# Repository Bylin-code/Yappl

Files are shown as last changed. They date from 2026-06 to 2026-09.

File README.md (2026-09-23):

# Yappl

Yappl is a small voice-journaling device built around a Seeed Studio XIAO ESP32S3. It has an animated face, a microphone, a button, a reminder light, and a piezo. Recordings stream over Wi-Fi to a backend running on your computer, where they are saved, transcribed locally, and optionally summarized with an AI provider. You can play back recordings and read your journal in a browser.

Build and test the electronics on a breadboard first. Follow the configuration, upload, and backend steps below and complete a test recording before moving the electronics into the printed chassis.

## 1. Bill of materials

| Quantity | Part | Notes |
| --- | --- | --- |
| 1 | Seeed Studio XIAO ESP32S3 | Standard board with 8 MB flash and 8 MB PSRAM; connect its Wi-Fi antenna. |
| 1 | SH1107 128 × 128 I2C OLED | Address `0x3C`, compatible with 3.3 V power and logic. An SSD1306 or SPI display is not a drop-in replacement. |
| 1 | INMP441 I2S microphone breakout | External microphone; this firmware does not use the Sense board's built-in microphone. |
| 1 | Normally open momentary pushbutton | Use contacts that connect only when pressed. |
| 1 | LED | External status/reminder LED; choose your preferred color. |
| 1 | Small passive piezo element | Not an active buzzer, magnetic buzzer, or speaker. |
| 1 | Bare photoresistor (LDR) | Room-light sensor. |
| 1 | 330 Ω resistor | LED current limiting. |
| 1 | 100 Ω resistor | Piezo series resistor. |
| 2 | 10 kΩ resistors | One for the light-sensor divider and one for the button pulldown. |
| 1 | USB-C data cable | Powers the board and uploads firmware; a charge-only cable cannot upload. |
| As needed | Breadboard, jumper wires, and headers | For the initial working prototype. |
| As needed | Insulated hookup wire, solder, and heat-shrink | For final connections inside the chassis. |
| 1 set | Printed enclosure parts | Files and printing instructions below. |
| As needed | FDM filament | Your choice of colors; use different colors for the cap and dots. |

You will also need an FDM printer, a soldering iron and basic hand tools, and a computer to upload firmware and run the backend. A multimeter is useful for checking continuity before power-up. Keep the backend computer powered on and awake during recording.

## 2. Print the enclosure

I'm using a **Bambu A1**, but **any FDM printer should work**. Use Bambu Studio for the A1 or your printer's slicer.

Print one of each:

- [`cad/body.stl`](cad/body.stl)
- [`cad/chassis-bottom.stl`](cad/chassis-bottom.stl)
- [`cad/chassis-top.stl`](cad/chassis-top.stl)
- The assembled hat from [`cad/hat-parts/`](cad/hat-parts/): `main-cap.stl` and `dot1.stl` through `dot8.stl`.

For the hat:

1. Select **all nine meshes** in `cad/hat-parts/` and import them together.
2. When prompted, import them as **a single object with multiple parts**. Preserve their relative positions; do not arrange each mesh independently on the plate.
3. Expand that object in the slicer's object list. Assign `main-cap.stl` one filament color and the `dot[x].stl` parts a different color. **The colors can be whatever you like.** The dots can share a color or use several colors, as long as they contrast with the cap.
4. Slice and preview the hat to confirm that the dots are correctly positioned and have the intended colors.

Use your printer's material profile and print the models at their original scale. PLA and a 0.20 mm layer height are reasonable starting points, not a required or validated print profile. Check orientation, bed contact, overhangs, and any required supports in the preview before printing. Test-fit the chassis and your electronics before permanent assembly; module dimensions and printer tolerances can vary.

Automatic multicolor printing requires suitable filament-changing hardware, such as an AMS Lite on the A1. With a single-color printer, you can print the assembled hat in one color and paint the dots afterward.

## 3. Wire and test on a breadboard

**Disconnect USB before changing wiring.** Power the XIAO through USB-C. Connect its `3V3` pin to the breadboard positive rail and `GND` to the ground rail. All components must share ground. Use **3.3 V** for peripherals and signal wiring; do not connect 5 V to GPIO pins. Attach the board's Wi-Fi antenna.

The table uses the **D labels printed on the XIAO**. The numbers in [`include/app/config.h`](include/app/config.h) are GPIO numbers, which are different.

| Component terminal | Connection | GPIO |
| --- | --- | --- |
| OLED VCC | 3V3 | — |
| OLED GND | GND | — |
| OLED SDA | D4 | 5 |
| OLED SCL | D5 | 6 |
| INMP441 VDD / VCC | 3V3 | — |
| INMP441 GND | GND | — |
| INMP441 SCK / BCLK | D8 | 7 |
| INMP441 WS / LRCLK | D9 | 8 |
| INMP441 SD / DOUT | D10 | 9 |
| INMP441 L/R / SEL | GND (left channel) | — |
| LED anode (+, usually the long leg) | D6 through 330 Ω | 43 |
| LED cathode (−, usually the short leg/flat edge) | GND | — |
| Passive piezo + | D7 through 100 Ω | 44 |
| Passive piezo − | GND | — |
| Photoresistor first leg | 3V3 | — |
| Photoresistor second leg | D0, also connected through 10 kΩ to GND | 1 |
| Button contact A | 3V3 | — |
| Button contact B | D1, also connected through a separate 10 kΩ to GND | 2 |

The light divider is `3V3 → photoresistor → D0 → 10 kΩ → GND`: brighter light should increase the reading. The button is `3V3 → switch → D1 → 10 kΩ → GND`: pressed reads HIGH. On a four-leg tactile switch, two legs may already be connected internally; use contacts that are disconnected when released and connected when pressed.

Keep microphone wires short. D2 and D3 are unused. D6 and D7 are used by the LED and piezo, so serial monitoring uses USB-C. See [`docs/xiao_wiring.md`](docs/xiao_wiring.md) for additional wiring notes.

Leave the circuit on the breadboard while completing steps 4–7. Once everything works, transfer it to the chassis using step 8.

## 4. Configure your home network

Download or clone this repository and open its root folder (the folder containing `platformio.ini`). Install Visual Studio Code with the PlatformIO IDE extension, and install and start Docker Desktop for the backend. Run the `pio` commands below in a PlatformIO terminal; this makes them available even if PlatformIO is not on your system PATH. Run Docker commands in a terminal with the Docker CLI available.

### Find the backend computer's LAN address

Connect the computer and XIAO to the same home network. The XIAO needs **2.4 GHz Wi-Fi**. Avoid a guest network that isolates devices from each other.

Find the computer's local IPv4 address in your network settings or router's device list. For example:

- macOS: System Settings → Wi-Fi → Details → TCP/IP. `ipconfig getifaddr en0` also works when Wi-Fi uses `en0`.
- Windows: run `ipconfig` and use the IPv4 address of the active Wi-Fi/Ethernet adapter.
- Linux: run `ip -4 addr` and use the address of the active LAN interface.

For the examples below, assume it is `192.168.1.25`. **Replace this with your actual address.** Use the computer's LAN address, not the XIAO's address, a Docker container address, or `localhost`. A DHCP reservation in your router helps keep it stable.

### Set firmware credentials

Copy [`include/secrets.example.h`](include/secrets.example.h) to `include/secrets.h`. If that file already exists, edit it instead of overwriting your settings. Replace its contents with this minimal configuration and fill in your own values:

```cpp
#pragma once

#define YAPPL_WIFI_NETWORKS { {"YOUR_HOME_WIFI_NAME", "YOUR_WIFI_PASSWORD"} }
#define YAPPL_BACKEND_BASE_URLS { "http://192.168.1.25:8000" }
#define YAPPL_DEVICE_ID "yappl_dev_001"
#define YAPPL_DEVICE_SECRET "PASTE_YOUR_DEVICE_SECRET_HERE"
```

Use the exact Wi-Fi name and password, keeping the quotation marks. Escape any literal `"` or `\` in those values as `\"` or `\\`. Remove unused example networks and backend URLs. Multiple entries are supported, but one of each is enough for a home setup.

Choose a device secret and use the **same value** in the backend configuration below. You can generate one with `openssl rand -hex 32` in a terminal with OpenSSL installed. Keep the device ID stable; it identifies this device's stored sessions. Use a different ID for each additional device.

In [`include/app/config.h`](include/app/config.h), leave `enableWifi`, `enableBackend`, and `enableTimeSync` set to `true`. The supplied pin configuration matches the wiring above. The default `timeZone` is a POSIX TZ string for Chicago/Central time:

```cpp
static constexpr const char *timeZone = "CST6CDT,M3.2.0/2,M11.1.0/2";
```

If you live elsewhere, replace it with the POSIX TZ rule for your location; this field does not accept an IANA name such as `America/Chicago`. Reminder timing uses this local clock. Rebuild and upload after changing either firmware configuration file.

### Prepare the backend configuration

Copy `backend/.env.example` to `backend/.env`, or edit the existing `.env`. Set:

```dotenv
YAPPL_ENV=local
YAPPL_DEVICE_SECRET=PASTE_THE_SAME_DEVICE_SECRET_HERE
YAPPL_STORAGE_DIR=/data
YAPPL_MP3_BITRATE=64k
YAPPL_TRANSCRIPTION_ENABLED=true
YAPPL_WHISPER_LANGUAGE=en
YAPPL_TRANSCRIPTION_TIMEOUT_SECONDS=1800
YAPPL_SUMMARY_ENABLED=true
YAPPL_SUMMARY_TIMEOUT_SECONDS=120
YAPPL_SETTINGS_SECRET=PASTE_A_SEPARATE_RANDOM_SECRET_HERE
ANTHROPIC_API_KEY=PASTE_YOUR_ANTHROPIC_API_KEY_HERE
```

Generate a separate random value for `YAPPL_SETTINGS_SECRET`, for example with another `openssl rand -hex 32`. Keep it stable: it protects provider keys saved through the settings API. Keep `/data` as the container storage path; Docker maps it to `backend/data/` on your computer.

The repository defaults to Anthropic for summaries. Supply your own API key with access to the configured model; summaries send transcript content to that provider and may incur API charges. To use recordings and local English transcription without a summary provider, set `YAPPL_SUMMARY_ENABLED=false` and leave `ANTHROPIC_API_KEY` empty. Additional provider configuration is described in [`backend/README.md`](backend/README.md).

Both `include/secrets.h` and `backend/.env` are ignored by Git. Do not commit passwords or API keys.

## 5. Build and upload the firmware

Connect the breadboarded XIAO to your computer with the USB-C data cable. From the repository root in a PlatformIO terminal:

```sh
pio run -e seeed_xiao_esp32s3
pio run -e seeed_xiao_esp32s3 -t upload
pio device monitor -b 115200
```

The first build downloads the toolchain and libraries. Wait for a successful build and upload. If several serial devices are connected, run `pio device list`, then specify the XIAO port:

```sh
pio run -e seeed_xiao_esp32s3 -t upload --upload-port YOUR_PORT
pio device monitor -b 115200 --port YOUR_PORT
```

Replace `YOUR_PORT` with a port such as `/dev/cu.usbmodem…` on macOS or `COM3` on Windows. If upload cannot connect, hold BOOT while plugging in USB, release BOOT, and retry. Reset the board after uploading if needed; its serial port may change. Exit the monitor with Ctrl+C before another upload.

Backend connection failures are expected at this point because the server has not been started yet. Do not start a recording until the next step is complete.

## 6. Start the backend

With Docker Desktop running, open a second terminal at the repository root:

```sh
cd backend
docker compose up -d --build
docker compose ps
curl http://localhost:8000/health
```

The initial build compiles `whisper.cpp` and downloads the local English transcription model, so it requires internet access and may take several minutes. The `api` service should be running, and `/health` should return JSON containing `"status":"ok"`.

Open **http://localhost:8000** on the backend computer to see the journal dashboard. On another device on the same network, open **http://192.168.1.25:8000/health**, using your computer's actual LAN address. This checks reachability beyond the backend computer itself. If necessary, allow inbound TCP port 8000 through the computer's firewall on your private home network.

The local dashboard has no login. Keep it on a trusted LAN; do not port-forward it to the public internet.

Watch server logs from the `backend` directory:

```sh
docker compose logs -f api
```

Ctrl+C stops following logs; the server keeps running. After changing `.env`, run `docker compose up -d --force-recreate` from this directory to apply the new environment. To stop the server, use `docker compose down`. Saved sessions remain in `backend/data/`.

## 7. Verify the complete device

### Check startup and electronics

Reset the XIAO with the backend running and watch its serial monitor. Look for:

- `Hardware: flash=8 MB psram=ready` with roughly 8 MB of usable PSRAM and no hardware-profile warning.
- `INMP441 ready` and successful audio-buffer allocation.
- `Wi-Fi connected. IP: ...`.
- `NTP time synced: ...` or `Clock synced from backend: ...`.
- `Backend ping OK: HTTP 200` and `Backend status OK: HTTP 200`. Normal checks occur about every 30 seconds.

Confirm that the OLED displays a face. Cover and uncover the photoresistor: `light=...%` should fall and rise. Speak near the microphone: `mic=...%` should respond. Press and release the button: `button=...` should change in the logs. Check the external LED and piezo during activation and deactivation.

### Make a test recording at any time of day

1. While idle, hold the button for **5 seconds** to start a session. This also clears the device's stored completion marker so you can start again outside the normal reminder window. If already in `reminder` mode, a **0.5-second** hold starts it.
2. Wait for `mode=listening`, then release the button fully. Look for `Backend session start OK: HTTP 200`.
3. Speak for 10–20 seconds. Keep the backend running and the device connected to Wi-Fi while recording.
4. Hold the button again for **1 second**, then release it to finish. Look for `Backend session finish OK: HTTP 200` and `Audio session finished: ... bytes=... dropped=0`. The byte count should be nonzero.
5. Refresh the dashboard at **http://localhost:8000**. Confirm the new session appears, play its audio, and check that the voice and duration sound correct. Allow time for local transcription, then check the transcript and, if enabled, summary. Follow backend logs for processing errors.

Session files are saved under `backend/data/devices/<device_id>/sessions/`. A completed, successfully processed session should contain `audio.mp3`, transcript files, and (when summaries are enabled and successful) `summary.txt`. A successful `/health` response alone does not verify recording, transcription, or summary generation; this test checks the whole path.

For everyday use, the default reminder window starts at **8 PM local time** and ends at midnight. A reminder requires no completed-session history or more than **12 hours** since the last completed session. A short idle press gives a “not yet” response; use the deliberate five-second hold to start outside that window.

## 8. Install the electronics in the chassis

After the breadboard passes the checks above:

1. Disconnect USB. Photograph or label the working wiring before removing it from the breadboard.
2. Dry-fit the electronics into the printed chassis and body. Check the OLED alignment, button travel, USB-C access, microphone opening, LED visibility, and light-sensor exposure before securing anything.
3. Insert and secure the electronics, leaving access to their terminals. Route and solder the final wires using the **same connection table in step 3**. Transfer one connection at a time, keep microphone wiring short, and retain all four resistors and the shared ground.
4. Insulate exposed joints and arrange wires so they cannot be pinched when fitting the chassis pieces, body, and hat. Keep the microphone opening clear and avoid loading the antenna connector or USB socket.
5. With power still disconnected, check every connection against the table and check for shorts between 3V3 and GND. Confirm LED polarity and the button's contact pairs.
6. Power the device with the enclosure still accessible and repeat the startup, sensor, and recording checks in step 7. Then close the enclosure and repeat a short recording to confirm assembly has not obstructed the microphone, button, or light sensor.

The repository provides STL meshes rather than a documented fastener/assembly kit; check your component fit before choosing a permanent mounting method.

## Troubleshooting

| Symptom | What to check |
| --- | --- |
| `pio` is not found | Use PlatformIO IDE's terminal in VS Code. |
| Upload fails or no USB port appears | Use a data cable, close the serial monitor, select the correct port, and try BOOT mode. |
| Hardware-profile warning | Confirm the standard XIAO ESP32S3 with 8 MB flash/PSRAM and the `seeed_xiao_esp32s3` build environment. |
| Wi-Fi fails | Check the antenna, 2.4 GHz network, SSID, and password in `include/secrets.h`; upload again and reset. |
| Backend requests fail | Check Docker, the computer's LAN IP, port 8000, firewall, and network isolation. Test `/health` from another LAN device. |
| Backend returns HTTP 401 | The firmware and backend `YAPPL_DEVICE_SECRET` values must match. Upload firmware and recreate the container after correcting them. |
| OLED is blank | Check SH1107/I2C compatibility, power, SDA/SCL, and address `0x3C`. |
| Mic is silent or audio is wrong | Check INMP441 power, D8/D9/D10 wiring, and L/R tied to GND. Inspect `mic` readings and play the saved recording. |
| Button or light reading is stuck | Check contact pairs, common ground, and the two separate 10 kΩ resistors. |
| Audio drops or recording is incomplete | Keep the backend awake and reachable; check Wi-Fi strength and logs. The device has only a short rolling audio buffer, not offline recording storage. |
| Transcript or summary is missing | Give processing time to finish and inspect `docker compose logs -f api`. Check provider credentials/model access for summaries, or confirm summaries were intentionally disabled. |
| Reminder time is wrong | Check `timeZone`, clock-sync logs, and the last completed session; rebuild/upload after firmware config changes. |

For implementation details, see the [system explainer](docs/system_explainer.md), [wiring reference](docs/xiao_wiring.md), and [backend guide](backend/README.md).

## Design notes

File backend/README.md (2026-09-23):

# Yappl Backend

## Deploy locally

Requirements: Docker Desktop.

```bash
cd backend
cp .env.example .env
# Edit .env and paste the Anthropic key after ANTHROPIC_API_KEY=
docker compose up -d --build
```

The first build compiles `whisper.cpp` and downloads the local English transcription model.

Verify:

```bash
curl http://localhost:8000/health
docker compose ps
```

Open the local journal dashboard on this computer:

```text
http://localhost:8000
```

Recordings are stored only in `backend/data/devices/<device_id>/sessions/`
(`/data/devices/<device_id>/sessions/` inside Docker).
The current device is `yappl_dev_001`. The backend does not read a separate
legacy session directory or use archive/demo storage.

Other devices on the same network can use the backend computer's LAN address,
for example `http://10.0.0.144:8000`. The dashboard is intentionally read-only
and has no login in local mode, so only expose port 8000 on a trusted network.

Run the backend test suite in the reproducible container environment:

```bash
docker compose run --rm api python -m unittest discover -s tests -v
```

View logs:

```bash
docker compose logs -f api
```

Stop:

```bash
docker compose down
```

Each completed session is transcribed locally and summarized using the selected
provider. The default is Anthropic `claude-sonnet-5`. Summaries are saved as
`summary.txt` beside that session's audio and transcript. Provider selection and
encrypted key storage are available through `GET/PUT /settings/summary`.

Personal memory is stored locally in `/data/memory.sqlite3`. Yappl preserves
`transcript.raw.txt`, writes name corrections to `transcript.corrected.txt`, and
uses relevant people/project facts as summary context. Manage memory through
`GET /memory/entities` and `PUT /memory/entities/{entity_id}`.

The ESP32 must use the host computer's LAN address, for example:

```text
http://10.0.0.144:8000
```

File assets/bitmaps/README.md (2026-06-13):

# Yappl Face Bitmap Sources

Put hand-drawn pixel art source files here later.

Recommended source format:

- 1-bit black/white PNG
- 96x64 px for the face area
- transparent or black background
- white pixels for lit OLED pixels

Current firmware placeholder assets are generated by:

```bash
python3 scripts/generate_face_assets.py
```

Generated firmware files:

- `include/assets/face_bitmaps.h`
- `src/assets/face_bitmaps.cpp`
- `include/assets/face_animations.h`
- `src/assets/face_animations.cpp`

Long term, this folder can hold PNG frames and the generator can be updated to
convert those PNGs instead of procedurally drawing placeholder eyes.

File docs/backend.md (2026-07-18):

# Yappl Backend and Docker Notes

## Purpose

Yappl will eventually need a backend so the physical device can send journal data somewhere permanent.

The backend is the cloud application that would receive data from the ESP32, store it, process it with AI, and make it available to a future phone app.

At a high level:

```text
Yappl device
  records audio / sends events
        |
        v
Backend API
  receives requests from the device
  stores data in a database
  talks to AI services
        |
        v
Phone app / web app
  shows summaries, transcripts, recordings, and progress
```

The firmware should not directly own all product data forever. The device should mostly collect data, show local status, and communicate with the backend.

## What the Backend Is

The backend is a program running on a computer or cloud server.

For Yappl, it would likely expose HTTP API routes such as:

```text
GET  /health
POST /device/session/start
POST /device/session/audio
POST /device/session/finish
GET  /entries
GET  /entries/{entry_id}
```

The ESP32 would call these routes over Wi-Fi.

Example:

```text
ESP32 -> POST /device/session/finish -> Backend
```

The backend would then save the session data and return a response.

## How HTTP Works

HTTP is the request/response protocol used by browsers, phone apps, servers, and the ESP32 when it talks to a web API.

The basic idea is:

```text
Client sends a request
        |
        v
Server receives it and does work
        |
        v
Server sends back a response
```

For Yappl:

```text
ESP32 device = HTTP client
Yappl backend = HTTP server
Phone app = HTTP client
```

The ESP32 does not "open" the backend directly like a person opens a website. It sends structured HTTP requests to API routes.

## HTTP Requests

An HTTP request has a few important parts:

```text
method
url
headers
body
```

Example Yappl request:

```http
POST /device/ping HTTP/1.1
Host: 192.168.1.25:8000
Content-Type: application/json
Authorization: Bearer local_device_secret

{
  "device_id": "yappl_dev_001",
  "wifi_connected": true,
  "time_synced": true
}
```

What each part means:

```text
POST
```

The method. `POST` usually means "send data to the backend."

```text
/device/ping
```

The route. This tells the backend which function should handle the request.

```text
Host: 192.168.1.25:8000
```

The server address. During local testing this may be your Mac's LAN IP address.

```text
Content-Type: application/json
```

This tells the backend that the request body is JSON.

```text
Authorization: Bearer local_device_secret
```

This is how the device can prove it is allowed to call the backend.

```json
{
  "device_id": "yappl_dev_001",
  "wifi_connected": true,
  "time_synced": true
}
```

This is the request body. It contains the actual data being sent.

## HTTP Responses

After the backend receives a request, it sends back an HTTP response.

Example response:

```http
HTTP/1.1 200 OK
Content-Type: application/json

{
  "status": "ok",
  "server_time": "2026-06-14T00:15:00-07:00"
}
```

The important parts are:

```text
status code
headers
body
```

```text
200 OK
```

The request worked.

```json
{
  "status": "ok",
  "server_time": "2026-06-14T00:15:00-07:00"
}
```

The backend returned JSON data that the device can read.

## HTTP Methods

HTTP methods describe what kind of action the client wants.

For Yappl, the most common methods will be:

```text
GET
  Read something from the backend.

POST
  Send new data to the backend.

PATCH
  Update part of something that already exists.

DELETE
  Delete something.
```

Examples:

```text
GET /health
  Ask if the backend is alive.

POST /device/ping
  Device checks in with the backend.

POST /device/session/start
  Device says a yap session started.

POST /device/session/audio
  Device uploads audio data.

POST /device/session/finish
  Device says a yap session ended.

GET /entries
  Phone app asks for journal entries.

GET /entries/{entry_id}
  Phone app asks for one specific journal entry.
```

## HTTP Status Codes

Status codes tell the client what happened.

Important ones for Yappl:

```text
200 OK
  The request worked.

201 Created
  Something new was created, like a new journal session.

400 Bad Request
  The device or app sent invalid data.

401 Unauthorized
  The device or app did not provide a valid secret/token.

404 Not Found
  The requested route or entry does not exist.

500 Internal Server Error
  The backend crashed or hit an unexpected bug.
```

The ESP32 firmware can use these codes to decide what to show on the OLED.

Example:

```text
200
  show normal connected state

401
  show backend auth error

500
  show backend error / try again later
```

## JSON

JSON is the main data format the backend, ESP32, and phone app should use for normal API calls.

Example JSON:

```json
{
  "device_id": "yappl_dev_001",
  "session_id": "session_123",
  "completed_at": "2026-06-14T00:20:00-07:00"
}
```

JSON is useful because:

```text
It is easy for humans to read.
It is easy for backend code to parse.
It is easy for phone apps to parse.
The ESP32 can generate it for small messages.
```

For large raw audio uploads, we may not use JSON for the audio bytes themselves. Audio may eventually be uploaded as binary data or chunked files.

## HTTP in Yappl's Local Setup

During local testing, the backend runs on your Mac.

Example:

```text
Backend URL on Mac:
http://localhost:8000
```

Your browser can use that URL because your browser is running on the same Mac.

The ESP32 cannot use that URL.

For the ESP32, `localhost` means:

```text
the ESP32 itself
```

So the ESP32 needs your Mac's Wi-Fi IP address instead.

Example:

```text
Backend URL from ESP32:
http://192.168.1.25:8000
```

Then the flow is:

```text
ESP32
  sends HTTP request over Wi-Fi
        |
        v
Router
        |
        v
Mac running backend
        |
        v
Backend sends HTTP response back
```

## HTTP in Yappl's Hosted Setup

Once the backend is hosted, the ESP32 and phone app use a public URL.

Example:

```text
https://api.yappl.example.com
```

Then the flow is:

```text
ESP32
        |
        v
Internet
        |
        v
Hosted Yappl backend
        |
        v
Database / storage / AI services
```

The phone app would use the same backend:

```text
Phone app
        |
        v
https://api.yappl.example.com
```

This is why the backend becomes the center of the product. The device and phone app are both clients.

## Example Yappl Session Flow Over HTTP

A simple future session could look like this:

```text
1. Device starts a session
   POST /device/session/start

2. Backend creates a session record
   returns session_id

3. Device uploads audio chunks
   POST /device/session/audio

4. Device finishes the session
   POST /device/session/finish

5. Backend transcribes and summarizes
   stores transcript and summary

6. Phone app loads the result
   GET /entries/{entry_id}
```

Example start request:

```http
POST /device/session/start HTTP/1.1
Content-Type: application/json
Authorization: Bearer local_device_secret

{
  "device_id": "yappl_dev_001",
  "started_at": "2026-06-14T00:15:00-07:00"
}
```

Example response:

```json
{
  "session_id": "session_123",
  "status": "recording"
}
```

The ESP32 would save `session_id` temporarily so future audio chunks are attached to the right journal session.

## HTTP vs Web Hosting

HTTP is the communication protocol.

Web hosting is where the backend runs.

They are related but different:

```text
HTTP
  The language clients and servers use to talk.

Hosting
  The place where the server is running.
```

Docker helps package the backend.

Hosting runs that packaged backend somewhere reachable.

HTTP is how the ESP32 and phone app communicate with it.

## Why Use Docker

Docker lets the backend run inside a controlled environment called a container.

Without Docker, the backend depends on whatever is installed directly on your Mac:

```text
Your Mac
  Python version
  installed packages
  database setup
  environment variables
```

That can become messy because different computers and servers may have different versions installed.

With Docker, the backend describes its own environment:

```text
Backend container
  specific Python version
  specific dependencies
  specific startup command
  specific exposed port
```

This means the backend can run almost the same way on your Mac now and on a cloud server later.

## Docker Mental Model

Your Mac is the host machine.

Docker runs isolated containers on top of it.

For Yappl, local development might look like this:

```text
Mac
  Docker
    api container
      runs the Yappl backend

    database container
      runs Postgres
```

The backend and database are separate containers.

They can talk to each other inside Docker, but your browser, phone app, or ESP32 talks to the backend through a port.

Example:

```text
http://localhost:8000
```

That means:

```text
localhost = your Mac
8000      = the backend API port
```

## Dockerfile

A `Dockerfile` explains how to build the backend container.

Example:

```dockerfile
FROM python:3.12-slim

WORKDIR /app

COPY requirements.txt .
RUN pip install -r requirements.txt

COPY app ./app

CMD ["uvicorn", "app.main:app", "--host", "0.0.0.0", "--port", "8000"]
```

What each part means:

```text
FROM python:3.12-slim
```

Start from a small Linux image that already has Python 3.12 installed.

```text
WORKDIR /app
```

Use `/app` as the main folder inside the container.

```text
COPY requirements.txt .
```

Copy the dependency list into the container.

```text
RUN pip install -r requirements.txt
```

Install the Python packages the backend needs.

```text
COPY app ./app
```

Copy the backend source code into the container.

```text
CMD [...]
```

Start the backend server when the container runs.

## Docker Compose

Docker Compose lets you run multiple containers together with one command.

For Yappl, the two main containers would be:

```text
api
  the backend server

db
  the Postgres database
```

Example `docker-compose.yml`:

```yaml
services:
  api:
    build: .
    ports:
      - "8000:8000"
    env_file:
      - .env

  db:
    image: postgres:16
    environment:
      POSTGRES_USER: yappl
      POSTGRES_PASSWORD: yappl_password
      POSTGRES_DB: yappl
```

Then you would run:

```bash
docker compose up --build
```

That command:

1. Builds the backend image.
2. Starts the backend container.
3. Starts the database container.
4. Shows logs in the terminal.

## Local Development Flow

Once backend code exists, the normal local flow would be:

```bash
cd backend
cp .env.example .env
docker compose up --build
```

Then test the backend:

```bash
curl http://localhost:8000/health
```

Expected response:

```json
{
  "status": "ok"
}
```

If that works, the backend is running.

## How the ESP32 Reaches the Backend

If the backend is running on your Mac, the ESP32 cannot use:

```text
http://localhost:8000
```

On the ESP32, `localhost` means the ESP32 itself, not your Mac.

For local testing, the ESP32 needs your Mac's local network IP address.

Example:

```text
http://192.168.1.25:8000
```

Then the flow is:

```text
ESP32
  connected to Wi-Fi
        |
        v
Mac on same Wi-Fi
  running backend at 192.168.1.25:8000
```

Later, when the backend is hosted, the ESP32 would call a real URL:

```text
https://api.yappl.example.com
```

## How This Transfers to Cloud Hosting

Docker is useful because many hosting platforms can run the same container.

The path can look like this:

```text
Local development
  docker compose on your Mac

Early hosted version
  Render / Fly.io / Railway / similar platform

Later production version
  AWS ECS / AWS Fargate / Elastic Beanstalk / similar AWS service
```

The backend code can stay mostly the same.

The main things that change are:

```text
Where the container runs
Where the database lives
What environment variables are configured
What public URL points to the backend
```

## Environment Variables

Backend settings should not be hardcoded directly into source files.

They should live in environment variables.

Examples:

```text
DATABASE_URL
OPENAI_API_KEY
YAPPL_DEVICE_SECRET
STORAGE_BUCKET
```

Local development usually uses a `.env` file:

```text
DATABASE_URL=postgresql://yappl:yappl_password@db:5432/yappl
YAPPL_DEVICE_SECRET=local_dev_secret
```

The `.env` file should not be committed to git if it contains real secrets.

Instead, commit an example file:

```text
.env.example
```

The real hosted backend would have these values configured in the hosting provider's dashboard.

## Database Role

The database stores structured information.

For Yappl, the database could store:

```text
users
devices
journal_sessions
transcripts
summaries
mood_tags
reminder_state
```

The database should not usually store large raw audio files directly.

A better structure is:

```text
Database
  session metadata
  transcript text
  summary text
  audio file URL

Object storage
  raw audio file
```

Object storage means something like S3 later.

## Audio Storage Role

Raw recordings can get large.

Instead of putting audio directly into Postgres, the backend should eventually upload recordings to file storage.

Possible future flow:

```text
ESP32 uploads audio
        |
        v
Backend receives audio
        |
        v
Backend stores file in object storage
        |
        v
Backend stores file URL in database
```

This keeps the database fast and manageable.

## AI Processing Role

The backend should own AI calls, not the ESP32.

Reason:

```text
ESP32
  limited memory
  limited processing power
  should not store API keys

Backend
  can safely store API keys
  can call AI APIs
  can retry failed requests
  can save generated summaries
```

The likely flow is:

```text
ESP32 records/sends audio
        |
        v
Backend transcribes audio
        |
        v
Backend summarizes journal entry
        |
        v
Backend saves transcript and summary
        |
        v
Phone app shows the result
```

The initial AI scope ends with transcription and daily summary generation.

## Future Phone App Role

The phone app should not talk directly to the ESP32 for journal history.

It should talk to the backend.

```text
Phone app
        |
        v
Backend
        |
        v
Database and audio storage
```

That lets the phone app show:

```text
daily summaries
raw transcripts
recordings
streaks
mood trends
progress over time
```

## Recommended First Backend Milestone

The first useful backend should be very small.

Start with:

```text
GET /health
  Confirms the backend is running.

POST /device/ping
  Confirms the ESP32 can reach the backend.

POST /device/session-completed
  Lets the ESP32 tell the backend that a yap session happened.
```

This would prove:

```text
ESP32 Wi-Fi works
ESP32 can call the backend
Backend can receive device events
Backend can store basic state
```

Only after that should audio upload, transcription, summaries, and phone app views be added.

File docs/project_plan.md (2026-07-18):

# Yappl Project Plan

This document sketches a possible final project structure for Yappl. It is planning-only and does not imply these folders should exist yet.

## Final Repository Shape

```text
Yappl/
  README.md
  platformio.ini
  .gitignore
  docs/
    vision.md
    project_plan.md
    hardware.md
    api.md
    firmware_architecture.md
    backend_architecture.md
    product_notes.md

  firmware/
    include/
      app/
        app_config.h
        app_state.h
        yappl_app.h
      drivers/
        button.h
        led.h
        oled_display.h
        inmp441_microphone.h
      services/
        audio_recorder.h
        network_manager.h
        api_client.h
        reminder_scheduler.h
        journal_session.h
        ui_controller.h
      util/
        ring_buffer.h
        time_utils.h
        logging.h

    src/
      main.cpp
      app/
        yappl_app.cpp
        app_state.cpp
      drivers/
        button.cpp
        led.cpp
        oled_display.cpp
        inmp441_microphone.cpp
      services/
        audio_recorder.cpp
        network_manager.cpp
        api_client.cpp
        reminder_scheduler.cpp
        journal_session.cpp
        ui_controller.cpp
      util/
        time_utils.cpp
        logging.cpp

    test/
      test_audio_level.cpp
      test_reminder_scheduler.cpp
      test_journal_session.cpp

  backend/
    README.md
    package.json
    src/
      server.ts
      config/
        env.ts
      routes/
        device_auth.ts
        journal_sessions.ts
        audio_upload.ts
        transcripts.ts
        summaries.ts
      services/
        transcription_service.ts
        summary_service.ts
        storage_service.ts
        device_registry.ts
      db/
        schema.ts
        migrations/
      jobs/
        summarize_session.ts
        cleanup_uploads.ts
      types/
        journal.ts
        device.ts
        api.ts
      tests/

  web/
    README.md
    package.json
    src/
      app/
      components/
      pages/
      lib/
      styles/

  scripts/
    firmware_upload.sh
    firmware_monitor.sh
    provision_device.sh
    capture_serial_log.py
    analyze_audio_samples.py

  tools/
    manufacturing/
      flash_device.sh
      device_self_test.md
```

## Firmware Responsibilities

The firmware should stay focused on device behavior and hardware control.

### `main.cpp`

Tiny Arduino entry point.

Responsibilities:

- Create the app object.
- Call `begin()`.
- Call `update()`.

### `app/`

Owns the product-level state machine.

Expected states:

- Booting.
- Wi-Fi setup.
- Idle.
- Reminder active.
- Session ready.
- Recording.
- Uploading.
- Processing summary.
- Completed.
- Error.

### `drivers/`

Low-level hardware wrappers only.

Expected drivers:

- OLED display.
- INMP441 microphone.
- Button.
- LED or breathing light.

Drivers should not know about journaling, AI, reminders, or backend behavior.

### `services/`

Reusable firmware features that combine drivers or external systems.

Expected services:

- `audio_recorder`: manages sample collection and buffering.
- `network_manager`: owns Wi-Fi connection and reconnect behavior.
- `api_client`: talks to the cloud backend.
- `reminder_scheduler`: decides when the device should remind the user.
- `journal_session`: owns start/stop/upload/session lifecycle.
- `ui_controller`: decides what text or visuals appear on the OLED.

### `util/`

Small shared helpers.

Examples:

- Logging.
- Time utilities.
- Ring buffers.
- Safe string formatting.

## Backend Responsibilities

The backend should protect cloud/API credentials and own long-term data.

Expected responsibilities:

- Device authentication.
- Audio upload or streaming.
- Transcription.
- Journal session storage.
- Summary generation.
- User-facing API for future app/web UI.

The ESP32 should not contain private AI provider API keys.

## Web/App Responsibilities

The web or phone-facing layer can come later.

Expected responsibilities:

- View journal history.
- Read transcripts.
- Read summaries.
- Listen to saved audio.
- View streaks/progress.
- Configure reminder time.
- Manage device pairing.

## Suggested Milestones

1. Stabilize current OLED mic meter.
2. Add one-button session start/stop.
3. Add LED reminder hardware.
4. Add Wi-Fi connection.
5. Add backend health-check API call.
6. Add simple audio upload.
7. Add backend transcription.
8. Store raw audio and transcripts.
9. Add nightly reminder logic.
10. Add session summaries.
11. Add web/app journal viewer.

## Near-Term Cleanup Direction

Before the project grows much more:

- Keep product firmware separate from debug firmware.
- Keep drivers hardware-focused.
- Avoid putting backend/API logic directly in `main.cpp`.
- Avoid hardcoding real Wi-Fi or API secrets in committed files.
- Treat scripts as developer tools, not firmware behavior.

## Notes on Current Repository

The current project is still a PlatformIO firmware repo. A final product may become a monorepo with firmware, backend, web app, docs, and tools.

Do not create the full final scaffold until each major area is actually needed.

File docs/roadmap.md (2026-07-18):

# Yappl Roadmap

This is the recommended step-by-step path for building Yappl from the current prototype into the final AI journaling device.

## 1. Stabilize the Current Hardware

Get the current ESP32-S3, OLED, and INMP441 mic working reliably.

Focus on:

- OLED meter draws correctly.
- Mic readings respond to speech.
- Firmware uploads and serial monitor are reliable.

Do not add Wi-Fi or backend work until the basic hardware loop is stable.

## 2. Add the Physical Controls

Add the real controls the product needs:

- One large button.
- Hidden on/off switch.
- Status LED or breathing light.

The button should start and stop a session. The LED should communicate idle, reminder, recording, and done states.

## 3. Add a Session State Machine

Create clear firmware states:

- Booting.
- Idle.
- Reminder active.
- Recording.
- Uploading.
- Done.
- Error.

Keep this local at first. The session can be fake before real audio upload exists.

## 4. Make Local Recording Work

Turn the mic from a level meter into a session recorder.

Start with:

- Button starts recording.
- Button stops recording.
- OLED shows recording state.
- OLED shows elapsed time.
- Firmware can hold or stream audio data without crashing.

At this stage, do not worry about AI.

## 5. Add Wi-Fi

Add Wi-Fi connection with hardcoded credentials first.

The device should:

- Connect on boot.
- Show failure clearly if Wi-Fi is unavailable.
- Reconnect if disconnected.
- Sync time with NTP.

Polished Wi-Fi provisioning can come later.

## 6. Create the First Backend

Build a small backend API.

Start with:

```text
GET /health
```

Then have the ESP32 call it and print/display whether the request worked.

Recommended early stack:

- Node.js + TypeScript backend.
- Render, Fly.io, Railway, or similar hosting.
- Supabase later for database and storage.

## 7. Add Device Authentication

Give the device a simple identity:

- `device_id`
- `device_secret`

The backend should reject requests without a valid device token.

Do not put OpenAI or other AI provider API keys on the ESP32.

## 8. Add Cloud Storage and Database

Set up the backend data model.

Likely tables:

```text
users
devices
journal_sessions
transcripts
summaries
```

Use object storage for recordings:

```text
recordings/{user_id}/{session_id}/audio.wav
```

## 9. Upload Audio

Start with non-live upload.

Flow:

```text
button press -> start session
button press -> stop session
device uploads audio
backend stores recording
backend marks session complete
```

Live streaming can wait.

## 10. Add Transcription

After audio upload works, have the backend transcribe the recording.

Flow:

```text
audio uploaded
backend sends audio to transcription API
backend stores transcript
```

The device should not call the transcription provider directly.

## 11. Add Session Summaries

Use the transcript to generate:

- Short summary.
- Key events.
- Mood/theme tags.
- Notable people.

Store the result in the backend.

## 12. Add Nightly Reminder Logic

Use time and session history to decide whether to remind the user.

Behavior:

- If no session today after bedtime window, breathe LED and show reminder.
- If room lights are off and still no session, optionally flash LED.
- If already completed, stay idle and calm.

This can use backend session status or local cached state.

## 13. Build the Phone App

Build the app after transcripts and summaries exist.

Use Expo / React Native.

First app screens:

- Session list.
- Session summary.
- Raw transcript.
- Recording playback.
- Streak/progress view.

Do not build a complex app before the backend has real data.

## 14. Improve Device UI

Polish the bedside experience:

- Better OLED text wrapping.
- Better idle screen.
- Better recording screen.
- Better reminder animation.
- Better error states.

The device should feel calm and intentional.

## 15. Add Product-Level Setup

Before anyone else can use it, add:

- Wi-Fi provisioning.
- Device pairing.
- User accounts.
- Better auth.
- Firmware update strategy.
- Device reset flow.
- Export/delete controls.

## 16. Productize the Hardware

After the interaction works:

- Design enclosure.
- Mount button cleanly.
- Mount OLED cleanly.
- Tune LED brightness.
- Make wiring robust.
- Add strain relief and power stability.

## Immediate Next Steps

1. Finish reliable OLED mic meter.
2. Add the button.
3. Add local session states.
4. Add Wi-Fi.
5. Add the first backend health check.

Backend summaries and the phone app should come after the device has a solid local recording flow.

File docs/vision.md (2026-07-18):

# Yappl Vision

## One-Sentence Description

Yappl is a bedside journalist that entices you to yap to it for about five minutes to record day-to-day life, with AI-powered summaries and progress tracking in the cloud.

## Audience

The first version is for personal use. The long-term hope is to turn it into a product for others.

## Personality and Feel

Yappl should feel like a playful journaling companion.

It should quietly record the user's journal entry without interrupting their train of thought. The OLED should communicate device state, reminders, recording progress, and completion.

The device will have a name and personality. It can be funny, but should remain useful and context-aware.

## Nightly Flow

Yappl is meant to be used before bed.

After a certain evening time, if the user has not completed a yap session for the day, the device should gently remind them with:

- A slowly breathing light.
- OLED text indicating that they have not journaled yet.

If the room lights are off and the user still has not yapped, the device may flash the light as a stronger reminder.

If the user has already completed a session, the device should stay idle and may show a calm visual on the OLED.

## Session Controls

The user starts a session with one large button.

The user also stops a session with the button. The session is not fixed to exactly five minutes; the user decides when to stop.

There should also be a hidden on/off switch.

## During a Yap Session

During a session, Yappl should:

- Listen to the user.
- Stream or upload audio to a cloud backend.
- Show a clear recording state and elapsed time.
- Avoid interrupting the user.

## Hardware Direction

Current hardware:

- ESP32-S3.
- 128x128 SH1107 OLED.
- INMP441 I2S microphone.

Planned or desired hardware:

- One large user-facing button.
- Hidden on/off switch.
- Status LED or breathing light.

The current 128x128 OLED is enough for now.

The device will sit on a bedside table and should be small, plugged in, and feel like a desk object rather than a generic gadget.

## Audio Behavior

Audio quality does not need to be studio-grade. It only needs to be understandable enough for transcription.

The device should detect silence and may display text during silence.

The cloud should store:

- Raw audio.
- Text transcription.
- AI summary.

Raw audio should not be deleted after transcription, though it may be compressed.

## AI Behavior

The AI should:

- Transcribe the completed session.
- Produce a useful daily summary afterward.
- Identify key events and notable details.
- Detect moods and themes.
- Remember previous entries.
- Surface patterns over time in summaries and progress views.

The AI should stay grounded in what the user actually recorded and avoid inventing details.

## Data and Privacy

All journal data should live in a cloud application built for Yappl.

Stored data should include:

- Audio.
- Raw transcripts.
- Summaries.
- Possibly metadata such as dates, moods, themes, and completion streaks.

Raw transcripts do not need a formal edit flow. They may be stored as text files or text records.

Exports to Markdown, PDF, or JSON may be useful later.

Encryption is not required for the personal MVP.

The system only needs to support one user for now.

## Connectivity

The device is expected to always have Wi-Fi because it lives in the user's room.

If Wi-Fi is down at bedtime, the device should not try to work offline. It should tell the user to connect to Wi-Fi or come back later.

Offline recording and later upload are not required.

Wi-Fi provisioning is undecided. Options include hardcoded Wi-Fi for early prototypes, captive portal setup, or phone-based setup later.

## Power and Form

The device will be plugged in.

Battery life is not a concern for the current direction.

The physical form should be small and feel like a desk object.

## MVP Scope

The simplest version worth using for one week:

- Records the user's voice.
- Produces transcripts.
- Reminds the user when they have not recorded anything that day.

Features that can wait:

- Phone app.
- Interface for browsing raw data and summaries.
- Rich progress tracking.

The session should not be limited to 30 seconds. The user decides when to stop.

## Backend Direction

A backend/server will be needed.

The backend should eventually handle:

- Device authentication.
- Audio upload or streaming.
- Transcription.
- AI summary generation.
- Journal storage.
- Future app/API access.

The backend should keep API keys and sensitive cloud credentials off the ESP32 device.

## Suggested Milestone Order

1. Make the normal OLED mic meter reliable.
2. Add the button and session state machine.
3. Add Wi-Fi connection and clear Wi-Fi failure UI.
4. Add a simple backend endpoint.
5. Upload short audio or test data from the device.
6. Add transcription on the backend.
7. Store transcript and audio in the cloud.
8. Add nightly reminder logic with LED and OLED.
9. Add summaries after each session.

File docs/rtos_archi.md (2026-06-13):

# RTOS Architecture for Yappl

This note explains how FreeRTOS would help Yappl, specifically for the current
ESP32-S3 prototype with:

- SH1107 OLED
- INMP441 microphone
- Button
- Photoresistor
- Status LED
- Passive piezo buzzer

## The Current Problem

The current firmware is cooperative:

```text
loop()
  app.update()
    read button
    read photoresistor
    read mic
    update LED
    update piezo
    draw OLED
```

This works until one operation takes a long time.

The OLED is the main issue. The display is 128x128 monochrome:

```text
128 * 128 / 8 = 2048 bytes
```

The full display buffer is sent over I2C. At 400 kHz, that transfer can take
roughly 45-60 ms. While that happens, the normal Arduino `loop()` is blocked.

That means:

- LED PWM updates pause.
- Piezo note timing pauses.
- Button reads pause.
- Mic reads pause.

This is why the LED fade can look stepped and the piezo scale can sound uneven.

## What RTOS Changes

FreeRTOS lets the firmware run multiple tasks.

Instead of one loop doing everything, each behavior gets its own loop:

```text
Output task:
  updates LED and piezo

Sensor task:
  reads button, photoresistor, mic level

Display task:
  draws the OLED

Main loop:
  mostly idle
```

The OLED can still be slow, but it blocks only the display task. The output
task can keep running.

RTOS does not make the OLED faster. It prevents the OLED from holding the whole
application hostage.

## Mental Model

Think of each task as a small independent worker.

Each task has:

- A job.
- A priority.
- A repeat rate.
- A stack size.

Example:

```text
Output task:
  job: LED breathing and piezo rhythm
  priority: high
  rate: every 5 ms

Sensor task:
  job: read inputs and mic level
  priority: medium
  rate: every 20-50 ms

Display task:
  job: render OLED from latest state
  priority: low
  rate: every 100-250 ms
```

Higher priority tasks get CPU time first.

## Recommended Yappl Task Layout

### 1. Output Task

Purpose:

- Keep LED animation smooth.
- Keep piezo rhythm steady.

Runs often:

```text
every 5 ms
```

Owns:

- app state transitions
- LED state patterns
- piezo state melodies

Reads:

- `buttonPressed`

Writes:

- `ledBrightness`
- `piezoFrequencyHz`

Priority:

```text
high
```

Reason:

Human perception notices LED stutter and rhythm jitter quickly. This task should
not wait behind OLED drawing.

### 2. Sensor Task

Purpose:

- Read button.
- Read photoresistor.
- Read mic level.

Runs:

```text
every 20-50 ms
```

Owns:

- `Button`
- `Photoresistor`
- `Inmp441Microphone`

Writes:

- `buttonPressed`
- `lightRaw`
- `lightLevel`
- `micLevel`

Priority:

```text
medium
```

Reason:

Inputs should feel responsive, but they do not need to update every millisecond.

### 3. Display Task

Purpose:

- Draw current app state on the OLED.

Runs:

```text
every 100-250 ms
```

Owns:

- `OledDisplay`

Reads:

- Button status
- Light level
- Mic level
- LED brightness
- Piezo status

Priority:

```text
low
```

Reason:

OLED updates are slow. The display should never control the timing of audio,
LEDs, or input handling.

### 4. Main Arduino Loop

Purpose:

- Nothing important.

After RTOS tasks are started, `loop()` can be mostly idle:

```cpp
void loop() {
  delay(1000);
}
```

The real application is running in FreeRTOS tasks.

## Shared App State

Tasks need to communicate through shared state.

Example:

```cpp
struct AppState {
  bool buttonPressed;
  int lightRaw;
  uint8_t lightLevel;
  uint8_t micLevel;
  uint8_t ledBrightness;
  uint16_t piezoFrequencyHz;
};
```

The sensor task writes input values.

The output task reads `buttonPressed` and writes LED/piezo status.

The display task reads everything and draws it.

## Avoid Direct Task Coupling

Do not do this:

```text
Sensor task directly calls display.draw...
Display task directly calls piezo.play...
Output task directly reads photoresistor...
```

That makes timing and ownership messy.

Better:

```text
Drivers own hardware.
Tasks own behavior timing.
Shared state carries facts between tasks.
```

## Protecting Shared State

Because multiple tasks can access state at the same time, protect it.

For Yappl, the simplest good option is a mutex:

```text
lock state
copy or update values
unlock state
```

Pattern:

```cpp
AppState snapshot;

xSemaphoreTake(stateMutex, portMAX_DELAY);
snapshot = appState;
xSemaphoreGive(stateMutex);

display.draw(snapshot);
```

Important rule:

Do not hold the mutex while doing slow work.

Bad:

```cpp
xSemaphoreTake(stateMutex, portMAX_DELAY);
display.drawFaceFrame(...);  // slow OLED I2C write
xSemaphoreGive(stateMutex);
```

Good:

```cpp
xSemaphoreTake(stateMutex, portMAX_DELAY);
snapshot = appState;
xSemaphoreGive(stateMutex);

display.drawFaceFrame(...);  // slow, but state is unlocked
```

This lets other tasks keep updating state while the OLED is busy.

## Task Timing

Use `vTaskDelayUntil()` for steady timing.

Better:

```cpp
TickType_t lastWake = xTaskGetTickCount();

while (true) {
  updateSomething();
  vTaskDelayUntil(&lastWake, pdMS_TO_TICKS(5));
}
```

Worse:

```cpp
while (true) {
  updateSomething();
  delay(5);
}
```

`vTaskDelayUntil()` tries to keep a fixed schedule. That is better for rhythm
and animation.

## Suggested Priorities

Starting point:

```text
Output task priority: 3
Sensor task priority:   2
Display task priority:  1
```

Avoid very high priorities unless needed.

A task should finish quickly, then delay/yield. A high-priority task that never
delays can starve the rest of the system.

## Suggested Stack Sizes

Starting point:

```text
Output task: 3072 bytes
Sensor task:   4096 bytes
Display task:  6144 bytes
```

Display gets the most stack because graphics libraries often use more stack.

If the ESP32 crashes with stack overflow messages, increase the stack for that
task.

## Core Pinning

ESP32-S3 has two cores.

For now, avoid overthinking core pinning. Use `xTaskCreate()` first.

If needed later:

```text
Core 0:
  Wi-Fi / system work

Core 1:
  output, sensors, display
```

Arduino already runs on top of FreeRTOS, so core behavior can depend on the
Arduino core and Wi-Fi usage.

Use pinning only when there is a real reason.

## How YapplApp Would Change

Current role:

```text
YapplApp::update()
  does everything
```

RTOS role:

```text
YapplApp::begin()
  initializes drivers
  creates shared state
  creates tasks
```

Then:

```text
output task owns output timing
sensor task owns input timing
display task owns OLED timing
```

`YapplApp` becomes the system coordinator, not the place where every behavior
runs.

## Possible File Structure

```text
include/
  app/
    app_state.h
    yappl_app.h

  services/
    output_task.h
    sensor_task.h
    display_task.h
    act_player.h

src/
  app/
    app_state.cpp
    yappl_app.cpp

  services/
    output_task.cpp
    sensor_task.cpp
    display_task.cpp
    act_player.cpp
```

Drivers stay as hardware wrappers:

```text
drivers/
  button
  photoresistor
  status_led
  piezo_buzzer
  oled_display
  inmp441_microphone
```

## Practical Migration Plan

### Step 1: Add AppState

Create a central state struct:

```cpp
struct AppState {
  bool buttonPressed = false;
  int lightRaw = 0;
  uint8_t lightLevel = 0;
  uint8_t micLevel = 0;
  uint8_t ledBrightness = 0;
  uint16_t piezoFrequencyHz = 0;
};
```

Add a mutex next to it.

### Step 2: Move LED and Piezo Into Output Task

This should be the first RTOS task because it fixes the visible problem.

The output task:

- Reads `buttonPressed`.
- Updates the app mode.
- Updates LED state patterns.
- Updates piezo state melodies.
- Writes `ledBrightness` and `piezoFrequencyHz`.
- Runs every 5 ms.

### Step 3: Move OLED Into Display Task

The display task:

- Copies a snapshot of `AppState`.
- Draws the OLED from that snapshot.
- Runs every 100-250 ms.

This isolates the slow I2C display transfer.

### Step 4: Move Inputs Into Sensor Task

The sensor task:

- Reads button.
- Reads photoresistor.
- Reads mic level.
- Writes values into `AppState`.
- Runs every 20-50 ms.

### Step 5: Keep Loop Empty

Once tasks own the behavior:

```cpp
void loop() {
  delay(1000);
}
```

## Debugging RTOS Problems

Common problems:

### One task starves the others

Cause:

- A high-priority task does not delay.

Fix:

- Add `vTaskDelayUntil()`.
- Lower priority.

### OLED still causes jitter

Cause:

- OLED library or I2C driver may hold CPU longer than expected.

Fixes:

- Lower OLED refresh rate.
- Draw less often.
- Try partial redraws later.
- Keep output task higher priority.

### Random crashes

Possible causes:

- Stack too small.
- Shared state accessed without mutex.
- Calling a non-thread-safe driver from two tasks.

Fixes:

- Increase stack size.
- Use mutexes.
- Make sure each hardware driver is owned by only one task.

### Button feels delayed

Cause:

- Sensor task period too slow.

Fix:

- Use 10-20 ms sensor period.
- Add debounce logic.

## Rules for Managing the System

1. One task should own each hardware driver.
2. Slow hardware belongs in low-priority tasks.
3. Timing-sensitive behavior belongs in high-priority tasks.
4. Shared state should be copied quickly under a mutex.
5. Never hold a mutex while doing OLED drawing, mic reads, serial printing, or
   other slow work.
6. Every task must delay or block regularly.
7. Keep task responsibilities boring and narrow.

## Best First RTOS Version for Yappl

The first useful RTOS version should have only three tasks:

```text
output task
sensor task
display task
```

Do not split into many tiny tasks yet.

That is enough to prove the main goal:

```text
OLED can update slowly without ruining LED smoothness or piezo rhythm.
```

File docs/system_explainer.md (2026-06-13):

# Yappl System Explainer

This document explains how the current Yappl firmware is structured and how the
RTOS version works.

It is written for someone new to RTOS concepts.

## Big Picture

Yappl currently runs on an ESP32-S3 using Arduino on top of FreeRTOS.

Arduino still provides:

- `setup()`
- `loop()`
- `pinMode()`
- `digitalRead()`
- `analogRead()`
- `tone()`
- `analogWrite()`

FreeRTOS provides:

- tasks
- task priorities
- task delays
- mutexes

The key change is this:

Old architecture:

```text
One loop did everything.
```

Current architecture:

```text
Several RTOS tasks run at the same time.
Each task owns one kind of work.
```

## Why RTOS Was Added

The OLED is slow.

The SH1107 OLED uses a 128x128 monochrome buffer:

```text
128 * 128 / 8 = 2048 bytes
```

Sending that buffer over I2C takes a noticeable amount of time.

When everything was inside one `loop()`, the OLED update blocked everything
else:

```text
OLED drawing starts
LED updates pause
piezo note changes pause
button reads pause
mic reads pause
OLED drawing ends
everything resumes
```

That caused:

- choppy LED fading
- uneven piezo rhythm

RTOS fixes this by letting OLED drawing happen in a low-priority task while the
LED and piezo continue in a higher-priority task.

## Current Task Split

The firmware now has four important execution areas:

```text
Arduino main loop
Output task
Sensor task
Display task
```

### Arduino Main Loop

File:

```text
src/main.cpp
```

The Arduino code is still the entry point:

```cpp
void setup() {
  app.begin();
}

void loop() {
  app.update();
}
```

But `app.update()` no longer runs the whole product.

It only idles:

```cpp
void YapplApp::update() {
  delay(1000);
}
```

This is intentional. The real work now happens in RTOS tasks.

### Output Task

The output task controls things the user sees/hears immediately:

- LED brightness
- piezo scale

It runs often:

```text
every 5 ms
```

This task needs to be smooth, so it has the highest priority of the Yappl tasks.

It owns these behavior services:

```text
state transitions
LED patterns
piezo melodies
```

The output task reads:

```text
buttonPressed
```

It writes:

```text
ledBrightness
piezoFrequencyHz
```

### Sensor Task

The sensor task reads inputs:

- button
- photoresistor
- microphone level

It runs:

```text
every 50 ms
```

It writes:

```text
buttonPressed
lightRaw
lightLevel
micLevel
```

This task is medium priority.

It is allowed to take longer than the output task because mic reads can block for
milliseconds.

### Display Task

The display task owns the OLED.

It runs:

```text
every 100 ms
```

It reads the latest state and draws:

- button state
- light level
- mic level
- LED brightness
- piezo status

This task is low priority because OLED drawing is slow.

The important rule:

```text
OLED drawing should not control LED or piezo timing.
```

## File Structure

Current important files:

```text
src/main.cpp
  Arduino entry point.

include/app/yappl_app.h
src/app/yappl_app.cpp
  Initializes hardware.
  Creates RTOS tasks.
  Owns shared app state and mutex.

include/app/app_state.h
  Defines the shared AppState struct.

include/app/config.h
  Hardware pins, feature flags, task periods, priorities, stack sizes.

include/drivers/
src/drivers/
  Low-level hardware wrappers.

include/services/
src/services/
  Behavior logic that sits above drivers.
```

## Drivers vs Services vs App

The project has three layers.

### Drivers

Drivers are low-level hardware wrappers.

Examples:

```text
Button
Photoresistor
StatusLed
PiezoBuzzer
OledDisplay
Inmp441Microphone
```

Drivers answer questions like:

```text
How do I read this pin?
How do I set this LED brightness?
How do I send text to this OLED?
How do I read mic samples?
```

Drivers should not know product behavior.

For example, `StatusLed` should not know what "recording" means.

It only knows:

```cpp
setBrightness(...)
```

### Services

Services contain behavior.

Current services:

```text
ActPlayer
```

`ActPlayer` knows which OLED face animation should play for the current app mode.

Services use drivers, but they still should not own the whole product.

### App

`YapplApp` coordinates the system.

It:

- initializes drivers
- creates the shared state mutex
- starts RTOS tasks
- owns the task entry functions

`YapplApp` is the glue.

It is not supposed to contain every detail of LED animation, piezo note order,
or OLED drawing.

## Shared AppState

Tasks need to share information.

That shared information lives in:

```text
include/app/app_state.h
```

Current state:

```cpp
struct AppState {
  bool buttonPressed = false;
  int lightRaw = 0;
  uint8_t lightLevel = 0;
  uint8_t micLevel = 0;
  uint8_t ledBrightness = 0;
  uint16_t piezoFrequencyHz = 0;
};
```

This is the current "truth" that tasks share.

Example:

```text
Sensor task reads the button.
Sensor task writes buttonPressed = true.
Output task reads buttonPressed = true.
Output task starts LED breathing and piezo scale.
Display task reads buttonPressed = true.
Display task draws "Button: PRESSED".
```

## Why a Mutex Exists

Multiple tasks can access `AppState`.

Without protection, this could happen:

```text
Display task starts reading AppState.
Sensor task changes AppState halfway through.
Display task gets a mixed old/new state.
```

That is called a race condition.

The project uses a mutex to prevent this.

A mutex is like a lock.

Only one task can hold the lock at a time.

Pattern:

```cpp
xSemaphoreTake(stateMutex_, portMAX_DELAY);
state_ = newValues;
xSemaphoreGive(stateMutex_);
```

The current app uses helper methods:

```cpp
stateSnapshot()
publishSensorState(...)
publishOutputState(...)
```

Those helpers hide the lock/unlock details.

## Important Mutex Rule

Do not hold the mutex while doing slow work.

Bad idea:

```text
lock state
draw OLED
unlock state
```

That would block other tasks from updating state while the OLED is doing a slow
I2C transfer.

Good idea:

```text
lock state
copy state into local snapshot
unlock state
draw OLED from local snapshot
```

That is what the display task does.

## How Each Task Runs

Each task is a function with an infinite loop:

```cpp
while (true) {
  doWork();
  waitUntilNextPeriod();
}
```

The current code uses:

```cpp
vTaskDelayUntil(...)
```

This means:

```text
Run this task on a steady schedule.
```

That is better than a normal delay for rhythms and animations.

## Task Periods

Task timing is configured in:

```text
include/app/config.h
```

Current periods:

```cpp
outputTaskPeriodMs = 5;
sensorTaskPeriodMs = 50;
displayTaskPeriodMs = 100;
serialLogMs = 500;
```

Meaning:

```text
Output task updates LED/piezo every 5 ms.
Sensor task reads sensors every 50 ms.
Display task redraws OLED every 100 ms.
Serial output prints every 500 ms.
Piezo changes notes every 180 ms.
```

## Task Priorities

Priorities are also in:

```text
include/app/config.h
```

Current priorities:

```cpp
outputTaskPriority = 3;
sensorTaskPriority = 2;
displayTaskPriority = 1;
```

Higher number means higher priority.

So:

```text
Output task runs before sensor task.
Sensor task runs before display task.
Display task runs last.
```

This is intentional.

OLED drawing is slow, so it gets the lowest priority.

LED/piezo timing should feel smooth, so output gets the highest priority.

## Task Stacks

Each task needs memory for its local variables and function calls.

This memory is called stack.

Current stack sizes:

```cpp
outputTaskStackBytes = 3072;
sensorTaskStackBytes = 4096;
displayTaskStackBytes = 6144;
```

Display gets the most stack because graphics libraries can use more memory.

If a task stack is too small, the ESP32 may crash or reboot.

## How Startup Works

Startup flow:

```text
Arduino calls setup()
setup() calls app.begin()
app.begin() starts Serial
app.begin() creates state mutex
app.begin() initializes OLED/mic/LED/piezo/photoresistor/button
app.begin() writes initial AppState
app.begin() starts output task
app.begin() starts sensor task
app.begin() starts display task
loop() idles forever
```

After that, the tasks run independently.

## How Button Press Behavior Works

When the button is not pressed:

```text
Sensor task writes buttonPressed = false.
Output task sees false.
Output task turns LED off.
Output task stops piezo.
Display task shows button open.
```

When the button is pressed:

```text
Sensor task writes buttonPressed = true.
Output task sees true.
Output task updates LED breathing every 5 ms.
Output task advances piezo notes on its own note clock.
Display task shows button pressed and current values.
```

The button does not directly control the LED.

Instead:

```text
button -> AppState -> output behavior
```

This keeps the system clean.

## Why the OLED Should Be Low Priority

The OLED is slow because it sends a lot of bytes over I2C.

If OLED had high priority, it could still hurt smooth output.

So the display task:

- copies state quickly
- releases the mutex
- spends time drawing
- waits until next display period

The output task can keep running between display work.

## How to Manage This System

Use these rules:

1. Keep drivers simple.
2. Put behavior in services.
3. Let tasks own timing.
4. Share facts through `AppState`.
5. Protect shared state with the mutex.
6. Do not hold the mutex during slow hardware calls.
7. Give slow work lower priority.
8. Give smooth/timing-sensitive work higher priority.
9. Every task must delay regularly.

## When Adding a New Feature

Ask these questions:

### Is it low-level hardware?

Put it in:

```text
drivers/
```

Example:

```text
new LED chip
new button type
new sensor
```

### Is it behavior?

Put it in:

```text
services/
```

Example:

```text
LED reminder pattern
button debounce
session timer
piezo sound pattern
```

### Does it need to share information?

Add fields to:

```text
AppState
```

Example:

```cpp
bool recording;
bool wifiConnected;
uint32_t sessionElapsedSec;
```

### Does it block or need special timing?

Consider a task.

Examples that deserve their own task later:

- audio recording
- Wi-Fi upload
- OLED display

Examples that probably do not need their own task:

- one LED pin
- one button pin
- one simple ADC read

## Common Mistakes

### Mistake: One task per tiny hardware part

This creates too many tasks and too much coordination.

Better:

```text
input task
output task
display task
audio task
network task
```

### Mistake: Tasks directly call each other

Avoid:

```text
sensor task tells display task what to draw
display task tells output task what sound to play
```

Better:

```text
tasks read/write shared AppState
product state decides behavior
```

### Mistake: Holding mutex during OLED drawing

This blocks other tasks from sharing state.

Always copy state first, then draw.

### Mistake: High-priority task never waits

If a high-priority task never calls `vTaskDelayUntil()` or otherwise blocks, it
can starve lower-priority tasks.

Every task loop needs a delay.

## Current System Summary

```text
Button/photoresistor/mic
  read by sensor task
  written into AppState

LED/piezo
  controlled by output task
  based on AppState.buttonPressed
  status written back into AppState

OLED
  controlled by display task
  draws a snapshot of AppState

Main loop
  idles
```

This structure keeps the slow OLED from ruining the timing of the LED and
piezo, while keeping the code organized enough to grow into the final Yappl
device.

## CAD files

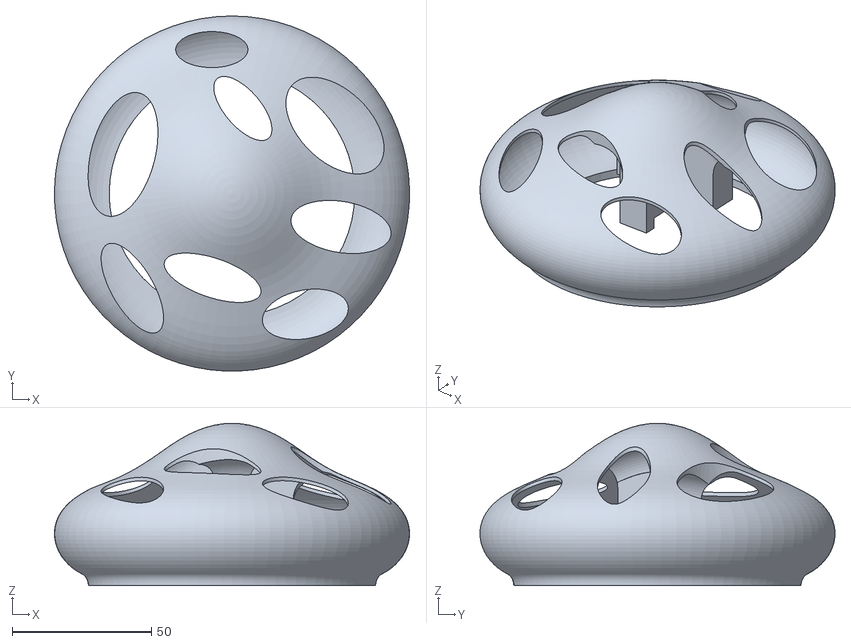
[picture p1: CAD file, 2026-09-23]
cad/hat-parts/main-cap.stl
127.7 x 127.7 x 58.4

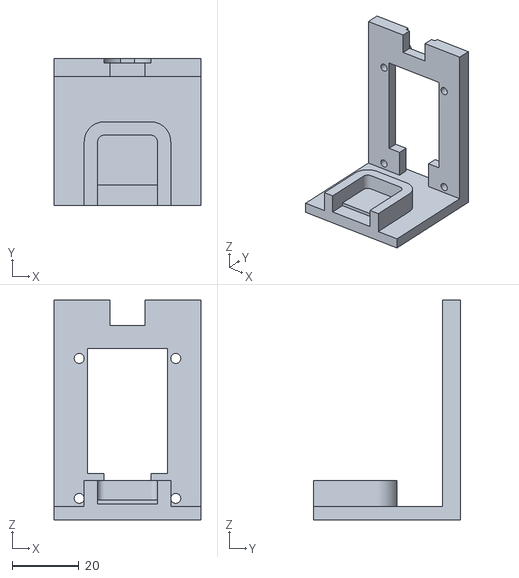
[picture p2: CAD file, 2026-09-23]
cad/chassis-bottom.stl
44.0 x 44.0 x 66.1

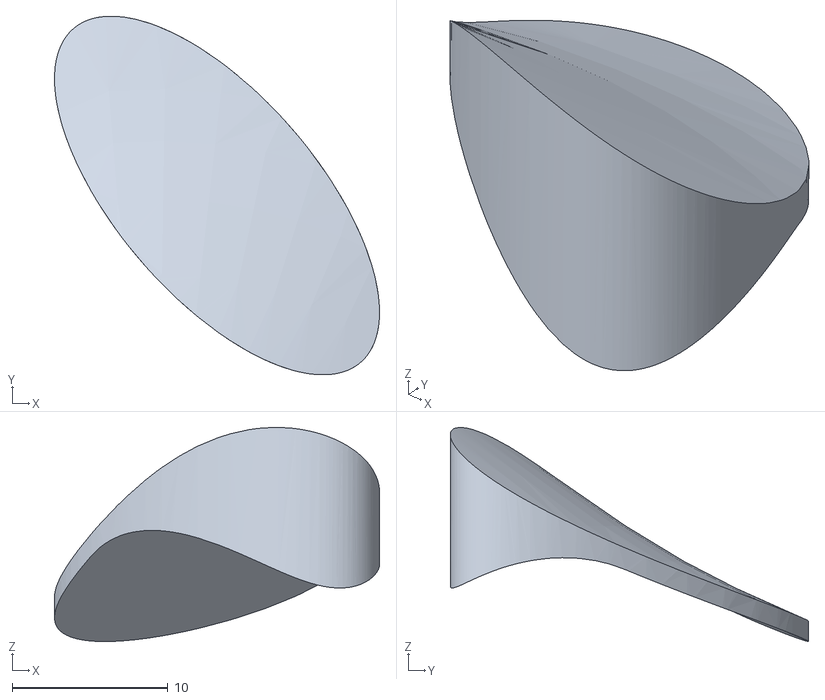
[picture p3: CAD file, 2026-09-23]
cad/hat-parts/dot7.stl
20.9 x 23.0 x 13.8

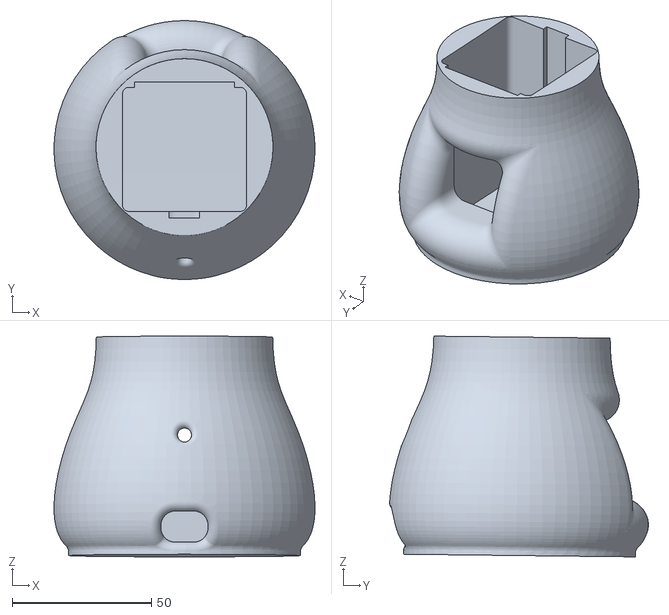
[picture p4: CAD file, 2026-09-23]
cad/body.stl
93.6 x 92.9 x 79.2

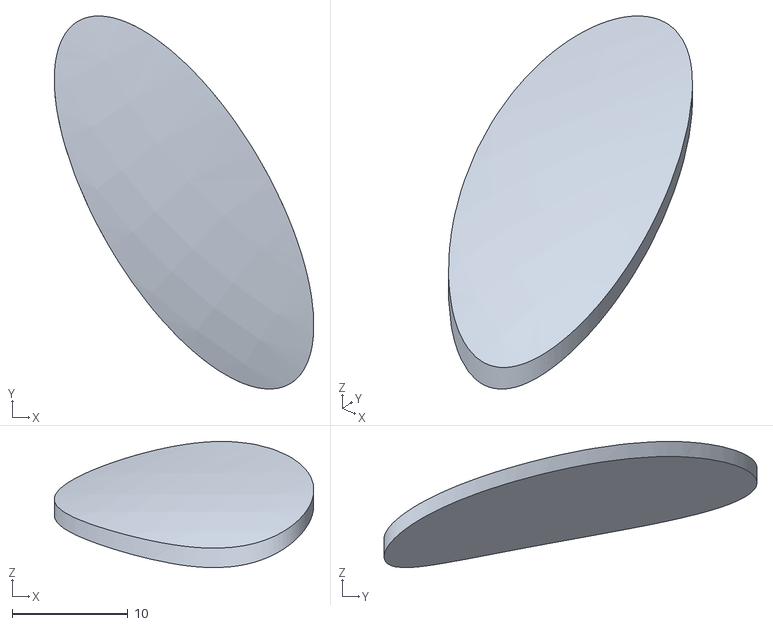
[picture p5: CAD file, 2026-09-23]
cad/hat-parts/dot1.stl
22.5 x 32.3 x 10.9

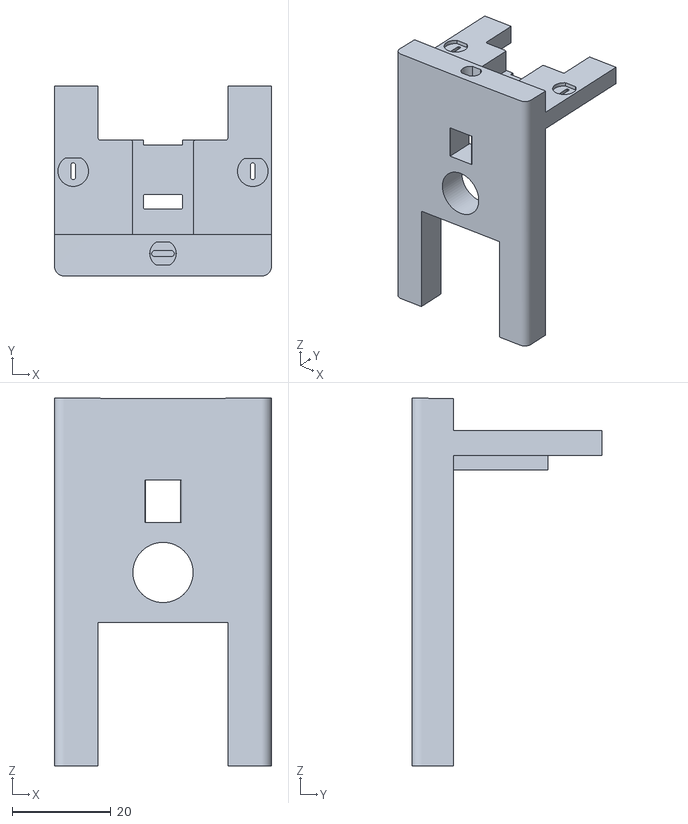
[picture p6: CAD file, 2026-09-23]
cad/chassis-top.stl
44.0 x 38.6 x 74.6

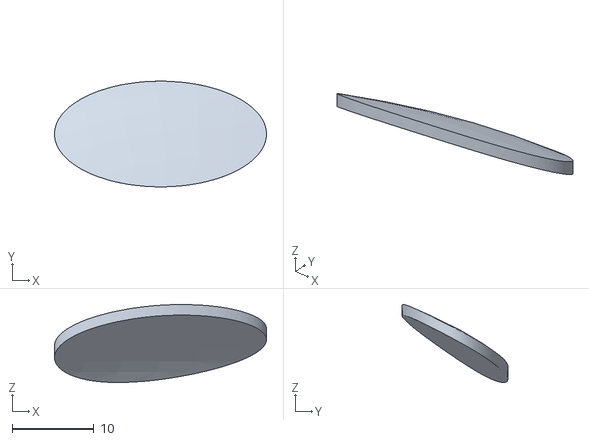
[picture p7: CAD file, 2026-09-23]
cad/hat-parts/dot8.stl
26.0 x 12.9 x 9.56

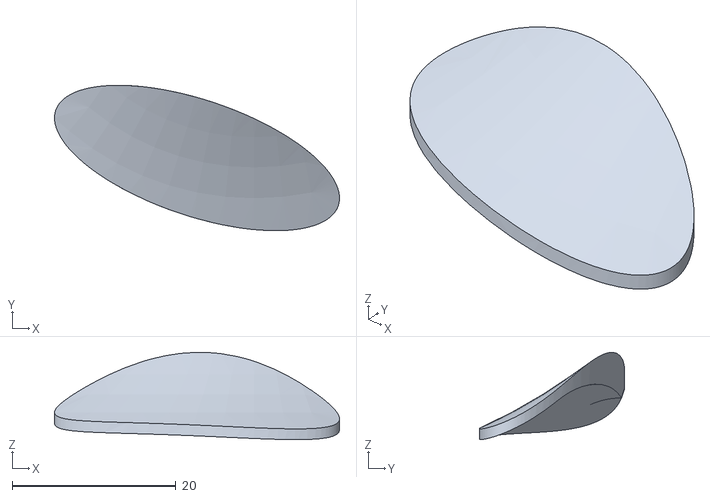
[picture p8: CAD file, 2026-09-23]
cad/hat-parts/dot3.stl
34.8 x 17.8 x 10.7

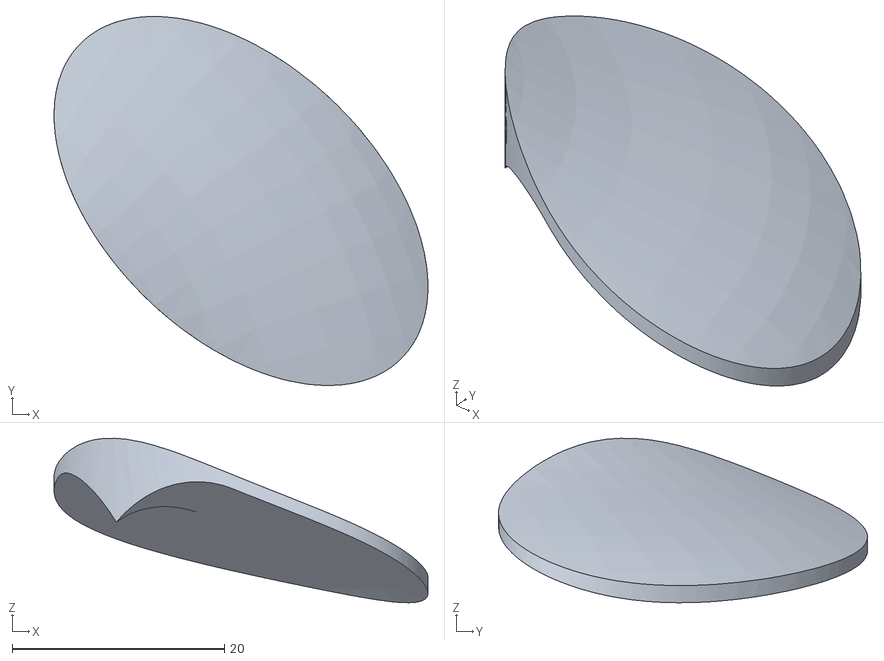
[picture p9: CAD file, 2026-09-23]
cad/hat-parts/dot6.stl
35.3 x 34.8 x 15.5

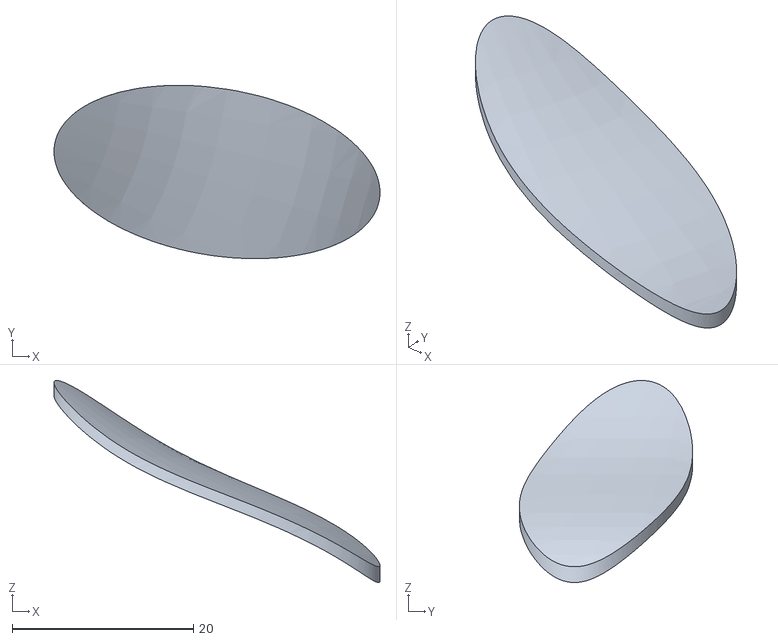
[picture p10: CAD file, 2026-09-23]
cad/hat-parts/dot5.stl
36.0 x 19.1 x 22.3

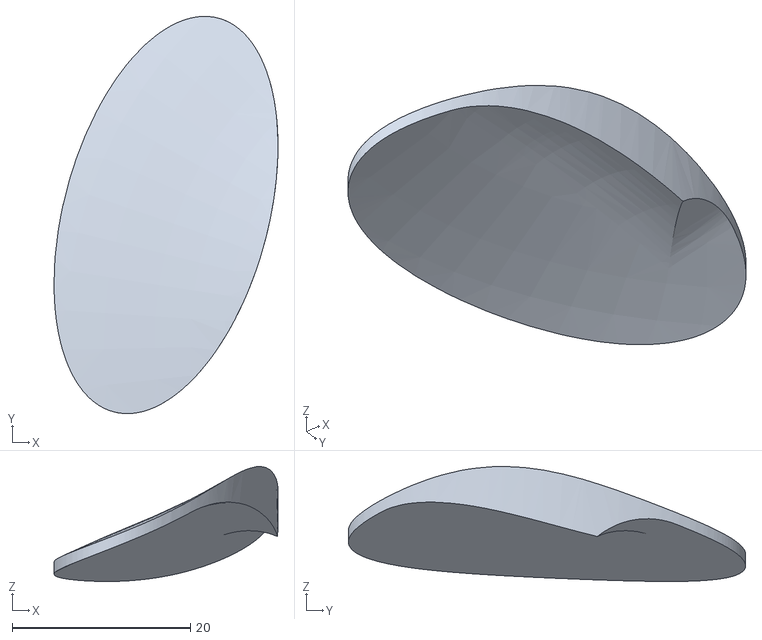
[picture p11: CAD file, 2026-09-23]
cad/hat-parts/dot4.stl
25.1 x 44.6 x 12.9

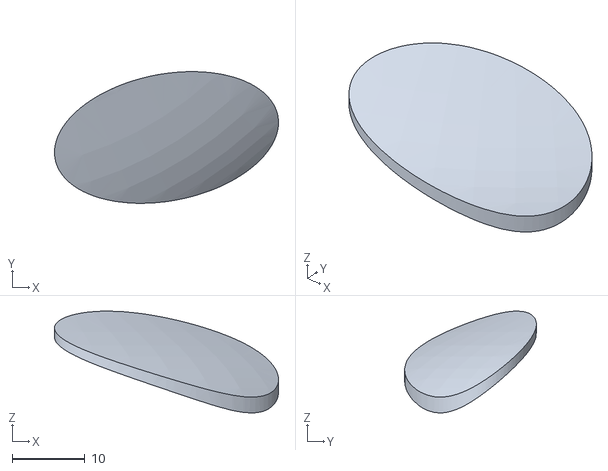
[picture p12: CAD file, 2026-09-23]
cad/hat-parts/dot2.stl
30.9 x 18.1 x 14.0

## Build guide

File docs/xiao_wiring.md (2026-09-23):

# Yappl wiring: Seeed Studio XIAO ESP32S3

Target: standard XIAO ESP32S3 (8 MB flash, 8 MB PSRAM), external INMP441,
128x128 SH1107 I2C OLED at address 0x3C, external LED, small passive piezo,
bare photoresistor, and normally open pushbutton. This firmware does not use
the Sense built-in PDM microphone, camera, or SD card. D8–D10 are assigned to
the external mic and cannot also serve the Sense SD card.

Disconnect USB before wiring. Use the board's printed pin labels; raw numbers
in `include/app/config.h` are GPIO numbers, not D numbers. Power the XIAO via
USB-C. Connect XIAO 3V3 to the breadboard positive rail and GND to its ground
rail. All components share this ground. Use 3.3 V for the peripherals and
signal pullups/dividers; do not connect 5 V to GPIO pins. Connect the supplied
antenna to the XIAO antenna socket for Wi-Fi.

## Connections

| Component terminal | Connect to | GPIO |
|---|---|---|
| OLED VCC | 3V3 rail | — |
| OLED GND | GND rail | — |
| OLED SDA | D4 | 5 |
| OLED SCL | D5 | 6 |
| INMP441 VDD / VCC | 3V3 rail | — |
| INMP441 GND | GND rail | — |
| INMP441 SCK / BCLK | D8 | 7 |
| INMP441 WS / LRCLK | D9 | 8 |
| INMP441 SD / DOUT | D10 | 9 |
| INMP441 L/R / SEL | GND rail (left channel) | — |
| External LED anode (+, usually long leg) | D6 through a 330 ohm resistor | 43 |
| External LED cathode (−, flat edge/short leg) | GND rail | — |
| Small passive piezo + | D7 through a 100 ohm series resistor | 44 |
| Small passive piezo − | GND rail | — |
| Photoresistor leg 1 | 3V3 rail | — |
| Photoresistor leg 2 | D0 and one end of a 10 kohm resistor | 1 |
| Other end of that 10 kohm resistor | GND rail | — |
| Button contact A | 3V3 rail | — |
| Button contact B | D1 and one end of a separate 10 kohm resistor | 2 |
| Other end of button's 10 kohm resistor | GND rail | — |

The photoresistor and resistors have no polarity. The photoresistor divider is
`3V3 -> photoresistor -> D0 -> 10 kohm -> GND`: brighter light raises the ADC
reading. The button is `3V3 -> switch -> D1 -> 10 kohm -> GND`: pressing reads
HIGH. On a four-leg tactile button, use two contacts that are disconnected
when released and connected when pressed; the two legs of each internally
connected pair are the same contact. Verify with continuity if unsure.

The piezo connection assumes a small passive piezo element, not a magnetic
buzzer, powered buzzer module, or speaker. Those require a suitable driver
circuit. The LED is external; the onboard LED is not used. The OLED must be
the existing SH1107 128x128 I2C module, not an SSD1306 or SPI display.

D2 and D3 are unused. D6 and D7 are repurposed for LED/piezo, so do not attach
a UART adapter there; serial logging uses USB-C. Keep microphone wires short.

## Build, upload, and check

```sh
pio run -e seeed_xiao_esp32s3
pio run -e seeed_xiao_esp32s3 -t upload
pio device monitor -b 115200
```

If automatic upload fails, hold BOOT while connecting USB, release BOOT, then
retry upload. Select the XIAO's USB port if more than one device is connected.
After upload, reset the board if needed and reopen the monitor if its port changes.

Startup should report 8 MB flash and 8 MB PSRAM. Check the OLED, button, LED,
piezo, light reading when covering/uncovering the sensor, and microphone
response to speech. Light thresholds and mic gain can be tuned in AppConfig.
Wi-Fi/backend credentials remain in `include/secrets.h`; the backend must be
reachable from the XIAO's network. A successful build does not verify wiring.

Compile the existing state-controller tests for this board with:

```sh
pio test -e xiao-tests --without-uploading --without-testing
```

To execute those tests on hardware, use `pio test -e xiao-tests`; this uploads
test firmware. Re-upload the normal application afterward.

Board references:
- [Seeed specifications and pinout](https://wiki.seeedstudio.com/xiao_esp32s3_getting_started/)
- [PlatformIO XIAO board](https://docs.platformio.org/en/latest/boards/espressif32/seeed_xiao_esp32s3.html)

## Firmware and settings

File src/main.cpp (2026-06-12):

#include <Arduino.h>

#include "app/yappl_app.h"

// Single global app object. Arduino calls setup()/loop(), but YapplApp starts
// the FreeRTOS tasks that do the real runtime work.
yappl::YapplApp app;

void setup() {
  app.begin();
}

void loop() {
  // Kept for Arduino compatibility. The app's update method intentionally
  // idles because output, sensor, and display work run in RTOS tasks.
  app.update();
}

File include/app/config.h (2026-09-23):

#pragma once

#include <Arduino.h>

namespace yappl {

// Centralized hardware map and behavior tuning. This file is the first place to
// edit when changing pins, fake time, task rates, or state durations.
struct AppConfig {
  // Standard Seeed XIAO ESP32S3: 8 MB flash and 8 MB OPI PSRAM.
  // Startup logs a mismatch if the connected hardware does not match.
  // Pin values below are GPIO numbers, not the printed D labels.
  // Complete wiring: docs/xiao_wiring.md.
  static constexpr uint32_t requiredFlashBytes = 8 * 1024 * 1024;
  // ESP.getPsramSize() reports usable heap, slightly below physical capacity.
  // Require at least 7 MiB usable on the 8 MiB module.
  static constexpr uint32_t requiredPsramBytes = 7 * 1024 * 1024;
  static constexpr bool requirePsram = true;
  // INMP441 sample rate. 16 kHz is enough for speech experiments and keeps
  // buffers smaller than 44.1/48 kHz audio.
  static constexpr uint32_t sampleRateHz = 16000;

  // Number of mic samples read per sensor task pass. At 16 kHz, 256 samples is
  // about 16 ms of audio. Larger values smooth the meter but block longer.
  static constexpr size_t micSampleCount = 256;

  // Audio uploaded to the backend is converted from INMP441 32-bit I2S slots
  // into signed 16-bit mono PCM. The mic task writes into a PSRAM rolling
  // buffer; the network task drains 8 KB batches. At 16 kHz mono 16-bit, 8 KB
  // is about 256 ms of audio and the 96 KB rolling buffer is about 3 seconds.
  static constexpr size_t audioUploadBatchBytes = 8 * 1024;
  static constexpr size_t audioRollingBufferBytes = 96 * 1024;

  // Simple digital gain applied only to uploaded recording audio. INMP441
  // speech at bedside distance can be quiet after converting 24-bit samples to
  // 16-bit PCM, so this boosts before clipping into int16_t.
  static constexpr int audioUploadGain = 4;

  // Simple mic meter scaling. Values below noiseFloor are treated as silence;
  // noiseCeiling maps to 100%. This is not calibrated SPL.
  static constexpr int noiseFloor = 0;
  static constexpr int noiseCeiling = 100000;

  // SH1107 OLED I2C wiring.
  static constexpr uint8_t oledAddress = 0x3C;
  static constexpr int oledSclPin = 6;  // D5
  static constexpr int oledSdaPin = 5;  // D4

  // INMP441 I2S input wiring. LR is wired to GND, so the driver reads left.
  static constexpr int micBclkPin = 7;   // D8
  static constexpr int micLrclkPin = 8;  // D9
  static constexpr int micDataPin = 9;  // D10

  // Simple IO wiring.
  static constexpr int ledPin = 43;           // D6, external active-high LED
  static constexpr int piezoPin = 44;         // D7, passive piezo
  static constexpr int photoresistorPin = 1;  // D0 / ADC1

  // ESP32 LED PWM settings. LEDC is the ESP32 hardware PWM peripheral.
  // Keeping this explicit avoids Arduino analogWrite auto-setup problems.
  static constexpr uint8_t ledPwmChannel = 0;
  static constexpr uint32_t ledPwmFrequencyHz = 5000;
  static constexpr uint8_t ledPwmResolutionBits = 8;

  // Button uses an external 10k pulldown, so pressed reads HIGH.
  static constexpr int buttonPin = 2;  // D1

  // Feature flags for isolating timing/load problems without deleting code. For
  // example, set enableOled=false to test if OLED I2C is causing jitter/noise.
  static constexpr bool enableOled = true;
  static constexpr bool enableMic = true;
  static constexpr bool enableLed = true;
  static constexpr bool enablePiezo = true;
  static constexpr bool enablePhotoresistor = true;
  static constexpr bool enableButton = true;
  static constexpr bool enableSerialLog = true;

  // Step-one internet flag. For now this only connects to Wi-Fi at boot and
  // prints status/IP over Serial; it does not call any cloud API yet.
  static constexpr bool enableWifi = true;

  // Backend API flag. When enabled and configured in include/secrets.h, Yappl
  // periodically pings the backend and reports completed yap sessions.
  static constexpr bool enableBackend = true;

  // HTTP requests run in the network task, not the timing-sensitive output
  // task. Keep this timeout short so a dead backend only delays status updates.
  static constexpr uint32_t backendHttpTimeoutMs = 2500;

  // How often the device sends a normal "I am alive" ping to the backend.
  static constexpr uint32_t backendPingPeriodMs = 30000;

  // How often the device asks the backend for device status.
  static constexpr uint32_t backendStatusPeriodMs = 30000;

  // Network task cadence. Audio upload is still HTTP-per-chunk, so this needs
  // to be much faster than once per second or recordings become very short.
  static constexpr uint32_t networkTaskPeriodMs = 100;

  // Limit each network task pass so audio uploads do not starve status pings.
  // Each batch is 8 KB, so one batch per 100 ms can move much faster than the
  // 32 KB/sec produced by the mic while staying simple.
  static constexpr uint8_t audioUploadBatchesPerNetworkPass = 1;
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

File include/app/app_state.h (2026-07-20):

#pragma once

#include <Arduino.h>

namespace yappl {

// These are the product-level modes from docs/prompts/behaviore.txt.
// The output task chooses the mode; the display task uses it to choose an act.
enum class AppMode : uint8_t {
  IdleDay,       // Recently yapped, daytime: calm awake face.
  Reminder,      // Has not yapped recently: remind with OLED/LED.
  NotYet,        // Short refusal animation after pressing during idle.
  Activation,    // Short happy transition before listening.
  Listening,     // Mic read/recording state.
  Deactivation,  // Good-night transition after ending listening.
  IdleNight,     // Recently yapped, nighttime: sleeping face.
};

// Small shared snapshot of the system. RTOS tasks pass information through this
// struct instead of directly calling each other.
struct AppState {
  // Product state selected by the output task.
  AppMode mode = AppMode::IdleDay;

  // Network status. This lets the OLED show Wi-Fi state even when Serial logs
  // are unavailable or the USB monitor is flaky.
  bool wifiConnected = false;
  bool backendConnected = false;
  bool audioUploading = false;
  bool timeSynced = false;
  uint8_t currentHour = 0;
  uint8_t currentMinute = 0;

  // Input/sensor values published by the sensor task.
  bool buttonPressed = false;
  int lightRaw = 0;
  uint8_t lightLevel = 0;
  uint8_t micLevel = 0;

  // Output values published by the output task for display/logging.
  uint8_t ledBrightness = 0;
  uint16_t piezoFrequencyHz = 0;

  // Number of PCM audio bytes queued for backend upload during this session.
  // It is diagnostic only; the backend is the source of truth for saved bytes.
  size_t recordedBytes = 0;
};

}  // namespace yappl

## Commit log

2026-06-12 added compatibility for button and led and button and piezo
2026-09-23 added readme and cad files
    [body.stl, chassis-bottom.stl, chassis-top.stl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]
